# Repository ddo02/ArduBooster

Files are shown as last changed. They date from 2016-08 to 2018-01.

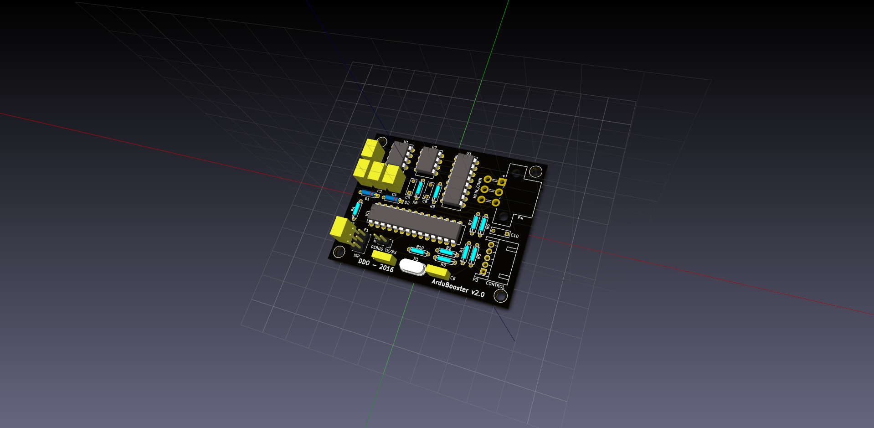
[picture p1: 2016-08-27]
3D_board.png

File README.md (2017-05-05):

# ArduBooster
TODO: Write the readme!

ArduBooster repository.

# License
This project is under dual-license.

First license is for commercial use of this project. To build a product, based on this project, and sell it.

Second license is for non-commercial use of this project. To build a sample, to personal use or education use.

# Donate


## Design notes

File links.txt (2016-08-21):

Arduino - AnalogWrite
https://www.arduino.cc/en/Reference/analogWrite

Arduino - Switch
https://www.arduino.cc/en/tutorial/switch

Arduino Tutorial - Lesson 3 - Breadboards and LEDs
http://www.ladyada.net/learn/arduino/lesson3.html

Arduino - Blink
https://www.arduino.cc/en/Tutorial/Blink?from=Tutorial.BlinkingLED

Fast PWM DAC
http://www.avdweb.nl/arduino/libraries/fast-pwm-dac.html

Arduino Playground - Timer1
http://playground.arduino.cc/code/timer1

Google Code Archive - Long-term storage for Google Code Project Hosting.
https://code.google.com/archive/p/arduino-timerone/

Analog Output - Convert PWM to Voltage - All
http://www.instructables.com/id/Analog-Output-Convert-PWM-to-Voltage/

Arduino’s AnalogWrite – Converting PWM to a Voltage
http://provideyourown.com/2011/analogwrite-convert-pwm-to-voltage/

(Sample)RC Low-pass Filter Design for PWM - Result -
http://sim.okawa-denshi.jp/en/PWMtool.php

Google
https://www.google.com.br/webhp?sourceid=chrome-instant&ion=1&espv=2&ie=UTF-8#q=diy+sprintbooster

www.crosslake.net/~dbipes/sprintbooster/SprintBooster.pdf
http://www.crosslake.net/~dbipes/sprintbooster/SprintBooster.pdf

Arduino - Map
https://www.arduino.cc/en/reference/map

map to floating point
http://forum.arduino.cc/index.php/topic=3922.0

connector sicma 4 vias - Pesquisa Google
https://www.google.com.br/search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

Cabex
http://www.cabex.com.br/produto/detalhe/id/83

404 Not Found
http://www.bmcom.com.br/lojas/papinjetores/produto.php?produto=1226

TC 104.1234 - TC Chicotes - Unitário | Canal da Peça
https://www.canaldapeca.com.br/p/1106702/tc-1041234-tc-chicotes-unitario

sprint-booster-circuit.jpg (660×469)
http://www.sprintbooster.ca/images/sprint-booster-circuit.jpg

www.intersil.com/content/dam/Intersil/documents/icl7/icl7660.pdf
http://www.intersil.com/content/dam/Intersil/documents/icl7/icl7660.pdf

Transistor Tutorial, history, sample circuits
http://www.sentex.ca/~mec1995/tutorial/xtor/xtor2/xtor2.html

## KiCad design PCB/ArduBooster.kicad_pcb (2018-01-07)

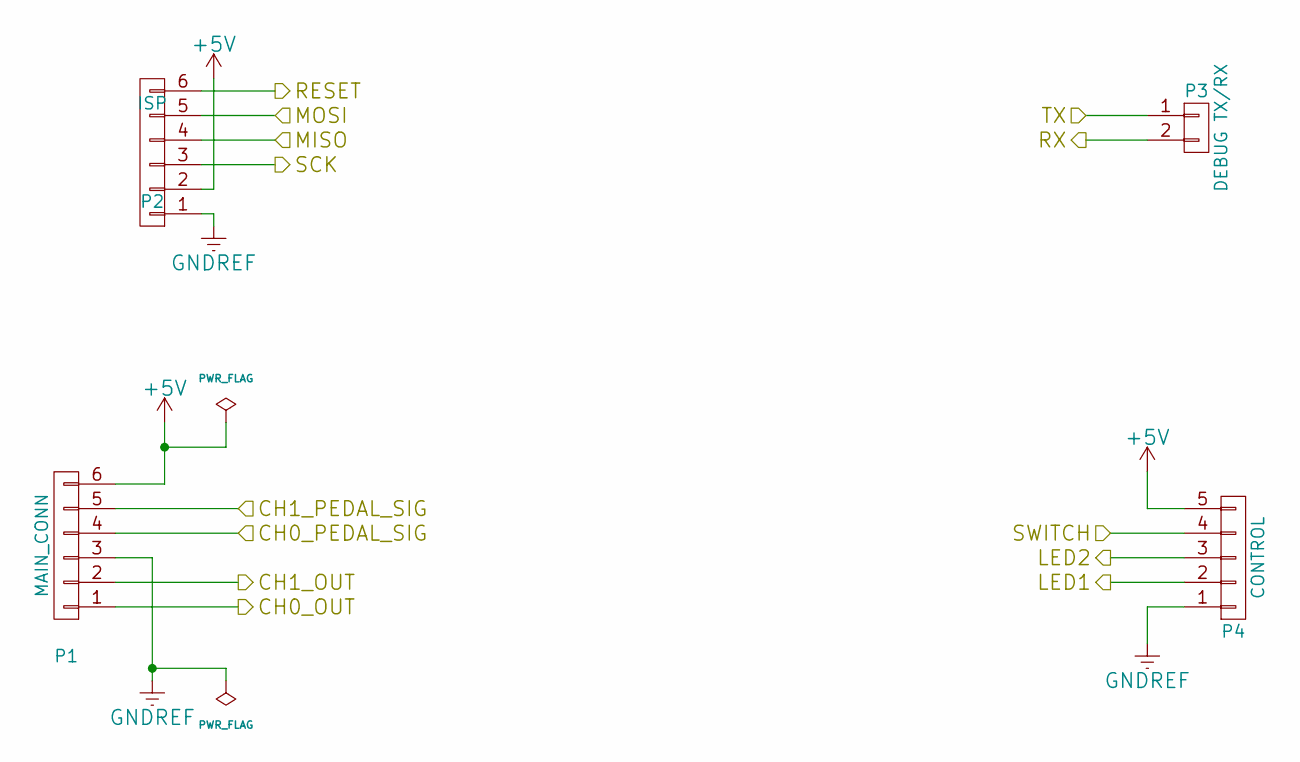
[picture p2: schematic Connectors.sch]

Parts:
P1: MAIN_CONN; Molex_MiniFit-JR-5569-06A1_2x03x4.20mm_Angled
P2: ISP; Pin_Header_Straight_1x06_Pitch2.54mm
P3: DEBUG TX/RX; Pin_Header_Straight_1x02_Pitch2.54mm
P4: CONTROL; Wafer_Horizontal15x5.8x7RM2.5-5

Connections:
+5V: P1.6, P2.2, P4.5; also elsewhere on the board
/Base Arduino/CH0_OUT: P1.1; also elsewhere on the board
/Base Arduino/CH0_PEDAL_SIG: P1.4; also elsewhere on the board
/Base Arduino/CH1_OUT: P1.2; also elsewhere on the board
/Base Arduino/CH1_PEDAL_SIG: P1.5; also elsewhere on the board
/Base Arduino/LED1: P4.2; also elsewhere on the board
/Base Arduino/LED2: P4.3; also elsewhere on the board
/Base Arduino/MISO: P2.4; also elsewhere on the board
/Base Arduino/MOSI: P2.5; also elsewhere on the board
/Base Arduino/RESET: P2.6; also elsewhere on the board
/Base Arduino/RX: P3.2; also elsewhere on the board
/Base Arduino/SCK: P2.3; also elsewhere on the board
/Base Arduino/SWITCH: P4.4; also elsewhere on the board
/Base Arduino/TX: P3.1; also elsewhere on the board
GNDREF: P1.3, P2.1, P4.1; also elsewhere on the board

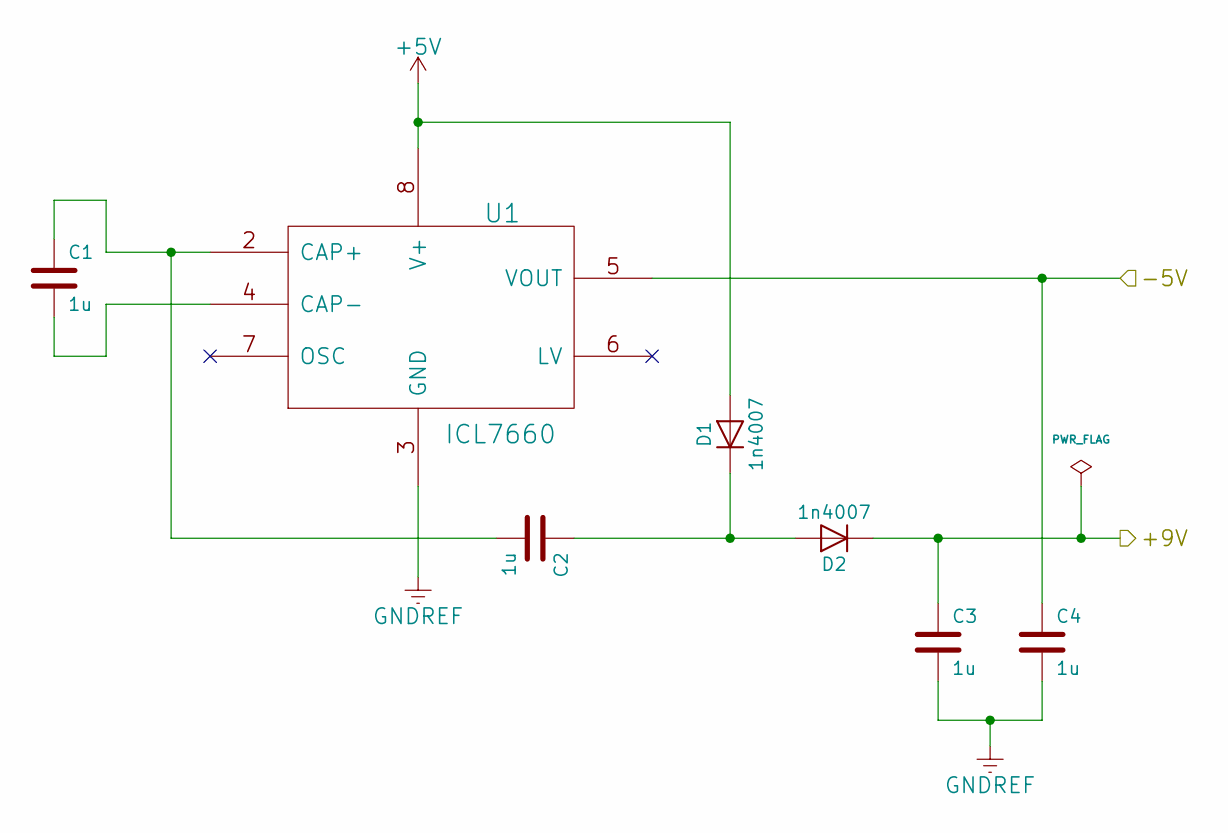
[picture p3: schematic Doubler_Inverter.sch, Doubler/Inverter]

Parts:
C1, C2, C3, C4: 1u; C_Rect_L7.0mm_W4.5mm_P5.00mm
D1, D2: 1n4007; D_A-405_P2.54mm_Vertical_AnodeUp
U1: ICL7660; DIP-8_W7.62mm_LongPads

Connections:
+5V: D1.2 (A), U1.8 (V+); also elsewhere on the board
/Doubler_Inverter/+9V: C3.1, D2.1 (K); also elsewhere on the board
/Doubler_Inverter/-5V: C4.1, U1.5 (VOUT); also elsewhere on the board
GNDREF: C3.2, C4.2, U1.3 (GND); also elsewhere on the board
unnamed: C1.1, C2.2, U1.2 (CAP+)
unnamed: C1.2, U1.4 (CAP-)
unnamed: C2.1, D1.1 (K), D2.2 (A)

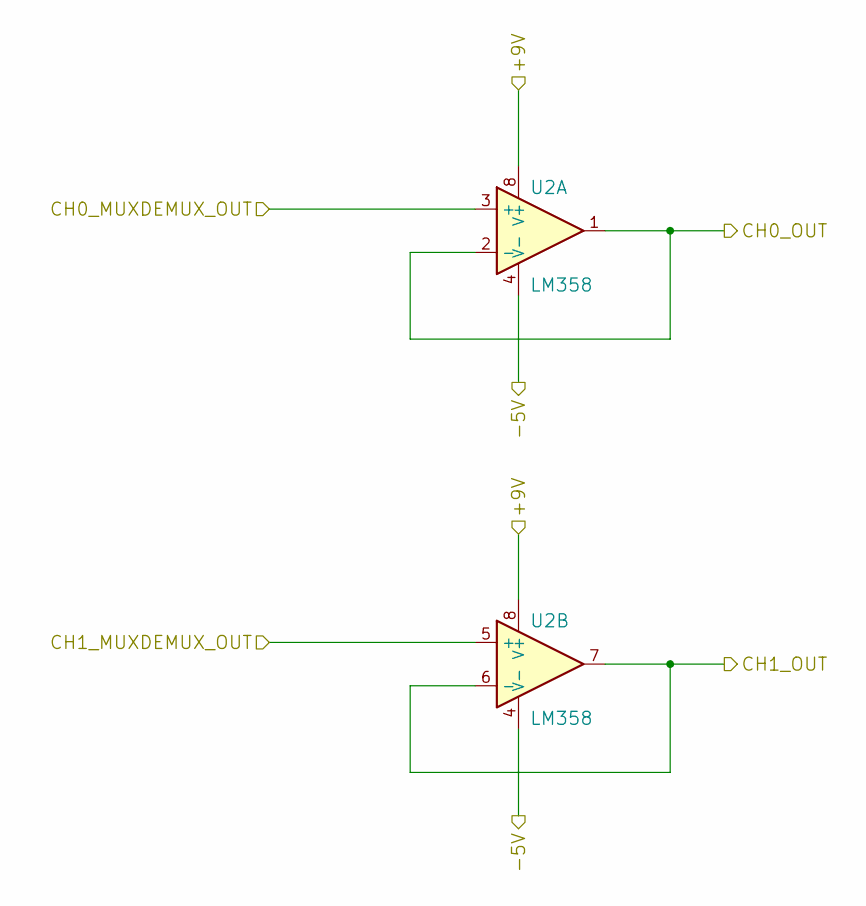
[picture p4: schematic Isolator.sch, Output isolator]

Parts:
U2: LM358; DIP-8_W7.62mm_LongPads

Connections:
/Base Arduino/CH0_OUT: U2.1, U2.2 (-); also elsewhere on the board
/Base Arduino/CH1_OUT: U2.6 (-), U2.7; also elsewhere on the board
/Doubler_Inverter/+9V: U2.8 (V+); also elsewhere on the board
/Doubler_Inverter/-5V: U2.4 (V-); also elsewhere on the board
/Isolator/CH0_MUXDEMUX_OUT: U2.3 (+); also elsewhere on the board
/Isolator/CH1_MUXDEMUX_OUT: U2.5 (+); also elsewhere on the board

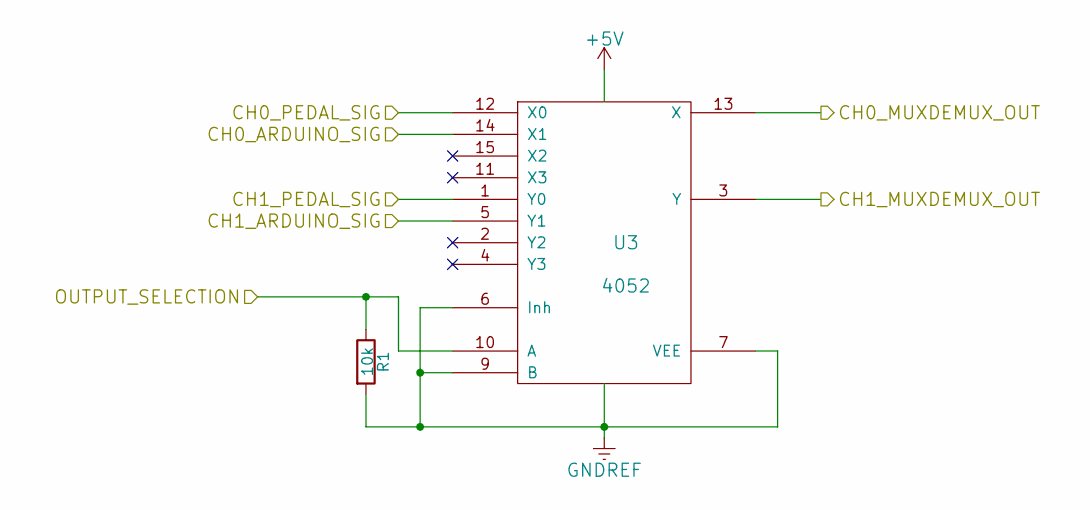
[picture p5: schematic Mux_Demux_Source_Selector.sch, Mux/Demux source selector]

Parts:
R1: 10k; R_Axial_DIN0207_L6.3mm_D2.5mm_P2.54mm_Vertical
U3: 4052; DIP-16_W7.62mm_LongPads

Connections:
+5V: U3.16 (VDD); also elsewhere on the board
/Base Arduino/CH0_ARDUINO_SIG: U3.14 (X1); also elsewhere on the board
/Base Arduino/CH0_PEDAL_SIG: U3.12 (X0); also elsewhere on the board
/Base Arduino/CH1_ARDUINO_SIG: U3.5 (Y1); also elsewhere on the board
/Base Arduino/CH1_PEDAL_SIG: U3.1 (Y0); also elsewhere on the board
/Base Arduino/MOSI: R1.1, U3.10 (A); also elsewhere on the board
/Isolator/CH0_MUXDEMUX_OUT: U3.13 (X); also elsewhere on the board
/Isolator/CH1_MUXDEMUX_OUT: U3.3 (Y); also elsewhere on the board
GNDREF: R1.2, U3.6 (Inh), U3.7 (VEE), U3.8 (VSS), U3.9 (B); also elsewhere on the board

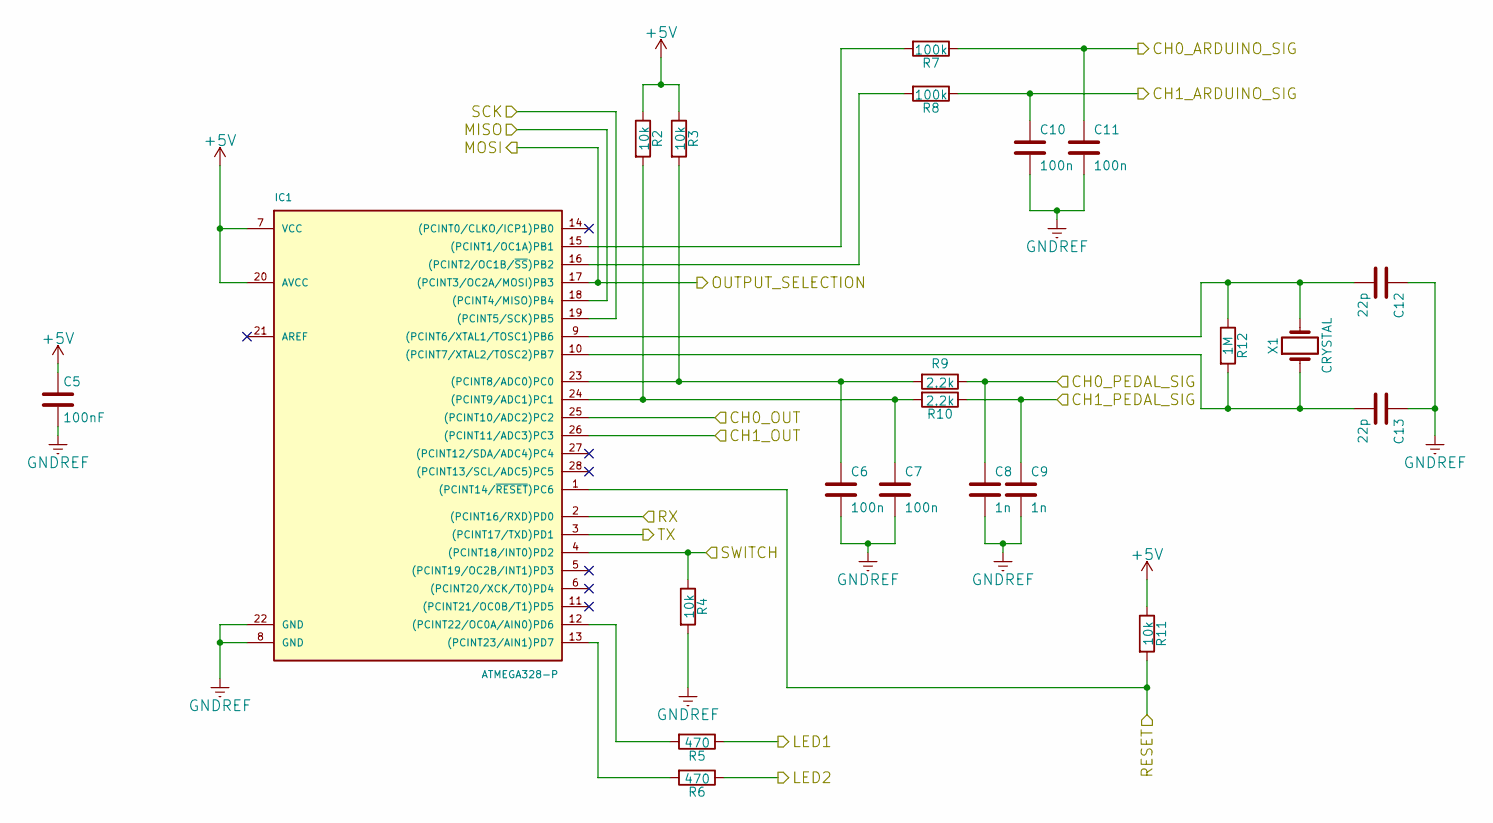
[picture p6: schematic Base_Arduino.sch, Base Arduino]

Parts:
C5: 100nF; C_Rect_L7.0mm_W2.5mm_P5.00mm
C6, C7, C10, C11: 100n; C_Rect_L7.0mm_W2.5mm_P5.00mm
C8, C9: 1n; C_Rect_L7.0mm_W2.0mm_P5.00mm
C12, C13: 22p; C_Rect_L7.0mm_W2.0mm_P5.00mm
IC1: ATMEGA328-P; DIP-28_W7.62mm_LongPads
R2, R3, R4, R11: 10k; R_Axial_DIN0207_L6.3mm_D2.5mm_P2.54mm_Vertical
R5, R6: 470; R_Axial_DIN0207_L6.3mm_D2.5mm_P2.54mm_Vertical
R7, R8: 100k; R_Axial_DIN0207_L6.3mm_D2.5mm_P2.54mm_Vertical
R9, R10: 2.2k; R_Axial_DIN0207_L6.3mm_D2.5mm_P7.62mm_Horizontal
R12: 1M; R_Axial_DIN0207_L6.3mm_D2.5mm_P2.54mm_Vertical
X1: CRYSTAL; Crystal_HC49-U_Vertical

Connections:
+5V: C5.1, IC1.7 (VCC), IC1.20 (AVCC), R2.1, R3.1, R11.1; also elsewhere on the board
/Base Arduino/CH0_ARDUINO_SIG: C11.1, R7.1; also elsewhere on the board
/Base Arduino/CH0_OUT: IC1.25 ((PCINT10/ADC2)PC2); also elsewhere on the board
/Base Arduino/CH0_PEDAL_SIG: C8.1, R9.1; also elsewhere on the board
/Base Arduino/CH1_ARDUINO_SIG: C10.1, R8.1; also elsewhere on the board
/Base Arduino/CH1_OUT: IC1.26 ((PCINT11/ADC3)PC3); also elsewhere on the board
/Base Arduino/CH1_PEDAL_SIG: C9.1, R10.1; also elsewhere on the board
/Base Arduino/LED1: R5.1; also elsewhere on the board
/Base Arduino/LED2: R6.1; also elsewhere on the board
/Base Arduino/MISO: IC1.18 ((PCINT4/MISO)PB4); also elsewhere on the board
/Base Arduino/MOSI: IC1.17 ((PCINT3/OC2A/MOSI)PB3); also elsewhere on the board
/Base Arduino/RESET: IC1.1 ((PCINT14/~RESET~)PC6), R11.2; also elsewhere on the board
/Base Arduino/RX: IC1.2 ((PCINT16/RXD)PD0); also elsewhere on the board
/Base Arduino/SCK: IC1.19 ((PCINT5/SCK)PB5); also elsewhere on the board
/Base Arduino/SWITCH: IC1.4 ((PCINT18/INT0)PD2), R4.1; also elsewhere on the board
/Base Arduino/TX: IC1.3 ((PCINT17/TXD)PD1); also elsewhere on the board
GNDREF: C5.2, C6.2, C7.2, C8.2, C9.2, C10.2, C11.2, C12.1, C13.1, IC1.8 (GND), IC1.22 (GND), R4.2; also elsewhere on the board
unnamed: C6.1, IC1.23 ((PCINT8/ADC0)PC0), R3.2, R9.2
unnamed: C7.1, IC1.24 ((PCINT9/ADC1)PC1), R2.2, R10.2
unnamed: C12.2, IC1.9 ((PCINT6/XTAL1/TOSC1)PB6), R12.1, X1.2
unnamed: C13.2, IC1.10 ((PCINT7/XTAL2/TOSC2)PB7), R12.2, X1.1
unnamed: IC1.12 ((PCINT22/OC0A/AIN0)PD6), R5.2
unnamed: IC1.13 ((PCINT23/AIN1)PD7), R6.2
unnamed: IC1.15 ((PCINT1/OC1A)PB1), R7.2
unnamed: IC1.16 ((PCINT2/OC1B/~SS~)PB2), R8.2

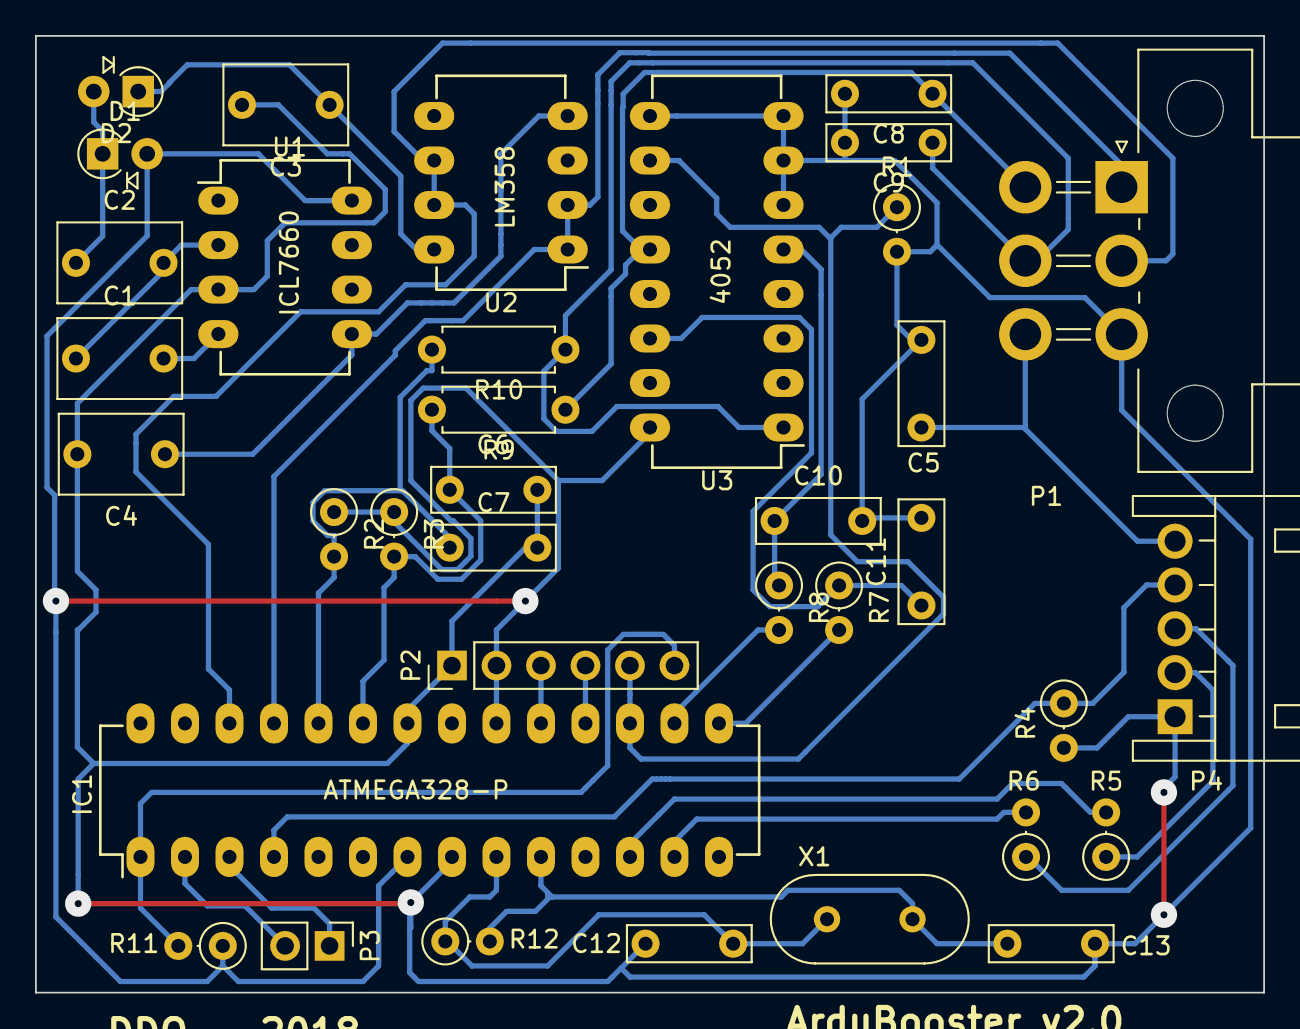
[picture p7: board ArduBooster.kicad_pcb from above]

Board: 2 copper layers, 70.1 x 54.6 mm, 36 parts (0 on the bottom side), 32 nets.

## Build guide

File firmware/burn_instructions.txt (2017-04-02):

Instructions to burn firmware on ArduBooster v1.0 board:

- Using an Arduino Uno (or compatible) board as a burner, to upload firmware to ArduBooster (Arduino as USB-to-Serial).
- Remove uC from Arduino board.
- Wire ArduBooster reset pin to Arduino reset pin.
- Wire ArduBooster Tx to Arduino Rx.
- Wire ArduBooster Rx to Arduino Tx.
- Connect Arduino Gnd and 5V to ArduBooster.
- On Arduino IDE, select the board according to used on ArduBooster (Arduino Uno recommended).
- BURN!!!

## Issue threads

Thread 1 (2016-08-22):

Small input pull up resistor

ddo02, 2016-08-22:
The used input pull up resistor (10k) can be small if working with POT sensor (works well with hall sensor).

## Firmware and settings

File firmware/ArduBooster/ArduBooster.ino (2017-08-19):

#include <EEPROM.h>
#include <avr/wdt.h>

#include "Filters.h"

// TODO LIST:
// Support to pedal with inverted signal (sensor 1 increase and sensor 2 decrease or vice-versa)
// Tests with POT pedal sensor
// Detect POT or HALL
// Use internal pull-up
// Auto find min sensor value (today, is readed is setup function)
// *OK* Enable watchdog * WD enabled
// *OK* Lower engineering margin :) (10% to 5% [?]) * 7%
// *NOK* Save max pesal value * This can be a problem, if change the car
// *NOK* Bypass when on idle * Not needed with PWM 10 bits

/** DEBUG FRAGS ***********************************************************************************/

// Enable/Disable serial debug
const bool DEBUG = false;

// Debug timer counter
unsigned int dbg_time_count = 0;
const unsigned long dbg_time = 50; // loops

/** END DEBUG FRAGS *******************************************************************************/

/** CONSTANTS *************************************************************************************/

// Boost mode 1 correction values (to use with map function)
const int MODE_1_MIN = 0;
const int MODE_1_MAX = 1535; // 50% (1023 to 1535)

// Boost mode 2 correction values (to use with map function)
const int MODE_2_MIN = 0;
const int MODE_2_MAX = 2046; // 100% (1023 to 2046)

// Max value to PWM
const int MAX_PWM = 1023;

// Number of times that ADC (sig0 and sig1) will be read to make a mean
const int BASE_VALUES_LOOP_COUNT = 10;

// Input signal pins, to read pedal position
const int sensorPot0Pin = A0;
const int sensorPot1Pin = A1;

// Feedback signal pins, to read and correct output signal
const int outputFeedback0Pin = A2;
const int outputFeedback1Pin = A3;

// Led mode pins
const int ledPin0 = 6;
const int ledPin1 = 7;

// Output signal pins
const int output0Pin = 9;
const int output1Pin = 10;

// Button pin (used to change boost mode)
const int buttonModePin = 2;

// Control pin, to enable/disable mux
const int enableMuxPin = 11;

const float filterCutFrequency = 100; // Hz

/** END CONSTANTS *********************************************************************************/

/** VARIABLES *************************************************************************************/

// Pedal values
int sensorPot0Value = 0;
int sensorPot1Value = 0;

// Maximum pedal value readed
int sensorPot0ValueMax = 0;
int sensorPot1ValueMax = 0;

// Output boost values
int output0Value = 0;
int output1Value = 0;

// Minimum pedal value, used to disable boost when the pedal is idle
int sensorPot0CutValue = 0;
int sensorPot1CutValue = 0;
int sensorPot0IdleValue = 0;
int sensorPot1IdleValue = 0;

// Proportion between sig0 and sig1
// Used to validate subsequent read
float sig_021_proportion = 2.0;

double first_vcc;
double current_vcc;

// Current boost mode
// 0 -> original
// 1 -> boost 1 (50%)
// 2 -> boost 2 (100%)
int mode = 0;

// Flag to determine if sensor is hall or not (potentiometer)
bool is_hall_sensor = true;

bool need_final_init = false;
bool need_find_sensor_type = false;

bool testing_sensor_0 = false;
bool testing_sensor_1 = false;

//FilterOnePole filter_pot_0(LOWPASS, filterCutFrequency);
//FilterOnePole filter_pot_1(LOWPASS, filterCutFrequency);

/** END VARIABLES *********************************************************************************/

/** METHODS ***************************************************************************************/

/*
Configure digital pins 9 and 10 as 10-bit PWM outputs.
With this config, PWM frequency is about 15khz
*/
void setupPWM10bits() {
  
  Serial.println("Starting PWM 10-bit...");
  
  DDRB |= _BV(PB1) | _BV(PB2);        // Set pins as outputs
  TCCR1A = _BV(COM1A1) | _BV(COM1B1)  // Non-inverting PWM
      | _BV(WGM11);                   // Mode 14: fast PWM, TOP=ICR1
  TCCR1B = _BV(WGM13) | _BV(WGM12)
      | _BV(CS10);                    // No prescaling
  ICR1 = 0x400;                       // TOP counter value (1024/10bits)
}

/*
After configured (using setupPWM10bits function), 
use this function to write PWM 10-bit
*/
void analogWrite10b(uint8_t pin, uint16_t val) {
    switch (pin) {
        case  9: OCR1A = val; break;
        case 10: OCR1B = val; break;
    }
}

void readIdleValues() {
  
  // Calculate initial idle pedal position
  // To avoid boost when pedal is not pressed
  // TODO: auto find idle position
  
  unsigned int adc_0_sum = 0;
  unsigned int adc_1_sum = 0;
  
  for(int i=0; i<BASE_VALUES_LOOP_COUNT; i++) {
    adc_0_sum += analogRead(sensorPot0Pin);
    adc_1_sum += analogRead(sensorPot1Pin);
  }
  
  sensorPot0IdleValue = (adc_0_sum / BASE_VALUES_LOOP_COUNT);
  sensorPot1IdleValue = (adc_1_sum / BASE_VALUES_LOOP_COUNT);
  
  // Engineering margin of safety :)
  // TODO: smooth transition
  //sensorPot0CutValue = adc_0_val * 1.05;
  //sensorPot1CutValue = adc_1_val * 1.05;
  
  // Sig1 to sig2 proportion
  // Theoretically, sensorPot1IdleValue (or sensorPot0IdleValue) never will be zero
  sig_021_proportion = sensorPot0IdleValue / sensorPot1IdleValue;
  
  //Serial.println(adc_0_sum);
  //Serial.println(adc_1_sum);
  //Serial.println(sensorPot0IdleValue);
  //Serial.println(sensorPot1IdleValue);
  //Serial.println(sig_021_proportion);
}

/*
Change mux/demux to use arduino signal
*/
void enableBoost() {

  // First of all
  // Verifies if PWM output RC filter had time enough to get correct value
  // To current RC values (R=100k and C=100n, with 15KHz), this time is about 25ms
  
  static unsigned long firstTime = millis();
  static bool boostEnabled = false;
  unsigned long timeToRC = 25; //ms
  if(!boostEnabled && firstTime + timeToRC < millis()) {
    digitalWrite(enableMuxPin, HIGH);
    boostEnabled = true;
  }
}

/*
void initOutput() {
  
  // Only (at setup) put the input value to output pin
  // This will improves the PID
  
  sensorPot0Value = analogRead(sensorPot0Pin);
  sensorPot1Value = analogRead(sensorPot1Pin);
  
  output0Value = map(sensorPot0Value, 0, 1023, 0, MAX_PWM);
  output1Value = map(sensorPot1Value, 0, 1023, 0, MAX_PWM);
  
  analogWrite10b(output0Pin, output0Value);
  analogWrite10b(output1Pin, output1Value);
}
*/

/*
Find sensor type.
Potentiometer or hall effect (open collector)

*** TO USE THIS, NEED HARDWARE MODIFICATION. DESABLE EXTERNAL PULL-UPS ***
*/
void findSensorType() {
  
  Serial.println("Finding sensor type...");
  
  // pull-down
  pinMode(sensorPot0Pin, OUTPUT);
  pinMode(sensorPot1Pin, OUTPUT);
  digitalWrite(sensorPot0Pin, LOW);
  digitalWrite(sensorPot1Pin, LOW);
  
  sensorPot0Value = analogRead(sensorPot0Pin);
  sensorPot1Value = analogRead(sensorPot1Pin);
  
  //TODO: constant
  if(sensorPot0Value <= 20 && sensorPot1Value <= 20) {
    is_hall_sensor = true;
    
    pinMode(sensorPot0Pin, INPUT_PULLUP);
    pinMode(sensorPot1Pin, INPUT_PULLUP);
  } else {
    is_hall_sensor = false;
    pinMode(sensorPot0Pin, INPUT);
    pinMode(sensorPot1Pin, INPUT);
  }
  
  Serial.print("Sensor 0: ");
  Serial.println(sensorPot0Value);
  Serial.print("Sensor 1: ");
  Serial.println(sensorPot1Value);
  
  if(is_hall_sensor)
    Serial.println("HALL SENSOR");
  else
    Serial.println("POT SENSOR");
}

ISR(ADC_vect)
{
} 

/*
Arduino setup
*/
void setup() {

  //analogReference(INTERNAL);
  
  // Enable ADC interrupt (call function ISR)
  //ADCSRA |= B00001000;
  
  // Init serial debug
  Serial.begin(9600);
  
  Serial.println("ArduBooster v2.0");
  Serial.println("Starting ArduBooster...");
  
  // Configure some pins
  pinMode(ledPin0, OUTPUT);  
  pinMode(ledPin1, OUTPUT);
  pinMode(output0Pin, OUTPUT);
  pinMode(output1Pin, OUTPUT);
  pinMode(buttonModePin, INPUT);
  pinMode(enableMuxPin, OUTPUT);
  
  //findSensorType();
  readIdleValues();

  first_vcc = readVcc()/1000.0;
  current_vcc = first_vcc;
  
  // TODO: 1.07 constant
  sensorPot0CutValue = sensorPot0IdleValue * 1.07;
  sensorPot1CutValue = sensorPot1IdleValue * 1.07;
  
  // Init PWM 10-bit
  setupPWM10bits();

  // Blink leds (initial boot)
  showBoot();
  
  // Load saved working mode
  mode = readMode();
  // Show working mode
  showMode(mode);
  
  Serial.println("ArduBooster started!");
  Serial.println("Enabling WD! Bye!!!");
  
  wdt_enable(WDTO_15MS);
}

// Arduino main loop
void loop() {
  
  //Serial.println(mode);

  
  //ADCValue = analogRead(0);
  //Voltage = (ADCValue / 1024.0) * Vcc;

  // read pedal values (0-1023)
  sensorPot0Value = analogRead(sensorPot0Pin);
  sensorPot1Value = analogRead(sensorPot1Pin);

  //Serial.println("=========");
  //Serial.println(sensorPot0Value);
  //Serial.println(sensorPot1Value);
  
  // TODO: delay problem???
  static int vcc_pass_count = 0;
  vcc_pass_count++;
  if (vcc_pass_count > 50) {
    //current_vcc = readVcc()/1000.0;
    vcc_pass_count = 0;
  }
  //sensorPot0Value = (sensorPot0Value * first_vcc) / current_vcc;
  //sensorPot1Value = (sensorPot1Value * first_vcc) / current_vcc;

  //Serial.println(first_vcc);
  //Serial.println(Vcc);
  //Serial.println(sensorPot0Value);
  //Serial.println(sensorPot1Value);
  //Serial.println("=========");
  
  //filter_pot_0.input(analogRead(sensorPot0Pin));
  //filter_pot_1.input(analogRead(sensorPot1Pin));
  //sensorPot0Value = filter_pot_0.output();
  //sensorPot1Value = filter_pot_1.output();
  
  // Compute max read value
  if (sensorPot0Value > sensorPot0ValueMax) {
    sensorPot0ValueMax = sensorPot0Value;
  }
  if (sensorPot1Value > sensorPot1ValueMax) {
    sensorPot1ValueMax = sensorPot1Value;
  }

  //TODO: Change this code to an interrupt
  //TODO: Need a small cap, to avoid multi interrupt fire
  // read button mode
  int buttonModeState = digitalRead(buttonModePin);
  // if pressed, change the boost mode
  static boolean pressed = false;
  if (buttonModeState == HIGH) {
    if(!pressed) {
      pressed = true;
      // Change to next boost mode
      mode = nextMode();
      showMode(mode);
    }
  } else {
    pressed = false;
  }
  
  //Serial.println(mode);
  //Serial.println("Sensor 0: ");
  //Serial.println(sensorPot0Value);
  //Serial.println("Sensor 1: ");
  //Serial.println(sensorPot1Value);

  //Serial.println("Cut 0: ");
  //Serial.println(sensorPot0CutValue);
  //Serial.println("Cut 1: ");
  //Serial.println(sensorPot1CutValue);
  //Serial.println();
  
  // Boost mode 1 (check if pedal is not in idle position, too)
  if(mode == 1 && sensorPot0Value > sensorPot0CutValue && sensorPot1Value > sensorPot1CutValue) {
    
    //Serial.println("BOOST 1");
    
    // Apply boost mode 1 correction
    
    int tmpOut0 = map(sensorPot0Value, 0, 1023, MODE_1_MIN, MODE_1_MAX);
    int tmpOut1 = map(sensorPot1Value, 0, 1023, MODE_1_MIN, MODE_1_MAX);
    
    // Veryfies if the corrected value isnt too big or too small
    // If the value is more than ECU max value (or min value), the ECU can put the engine in safe mode
    if (tmpOut0 > sensorPot0ValueMax) {
      tmpOut0 = sensorPot0ValueMax;
    }
    if (tmpOut1 > sensorPot1ValueMax) {
      tmpOut1 = sensorPot1ValueMax;
    }
    if (tmpOut0 < sensorPot0IdleValue) {
      tmpOut0 = sensorPot0IdleValue;
    }
    if (tmpOut1 < sensorPot1IdleValue) {
      tmpOut1 = sensorPot1IdleValue;
    }
    
    // Prepare to PWM
    output0Value = map(tmpOut0, 0, 1023, 0, MAX_PWM);
    output1Value = map(tmpOut1, 0, 1023, 0, MAX_PWM);
  } 
  // Boost mode 2 (check if pedal is not in idle position, too)
  else if(mode == 2 && sensorPot0Value > sensorPot0CutValue && sensorPot1Value > sensorPot1CutValue) {
    
    //Serial.println("BOOST 2");
    
    // Apply boost mode 2 correction
    
    int tmpOut0 = map(sensorPot0Value, 0, 1023, MODE_2_MIN, MODE_2_MAX);
    int tmpOut1 = map(sensorPot1Value, 0, 1023, MODE_2_MIN, MODE_2_MAX);

    //Serial.println("TPM 0: ");
    //Serial.println(tmpOut0);
    //Serial.println("TMP 1: ");
    //Serial.println(tmpOut1);

    // Veryfies if the corrected value isnt too big or too small
    // If the value is more than ECU max value (or min value), the ECU can put the engine in safe mode
    if (tmpOut0 > sensorPot0ValueMax) {
      tmpOut0 = sensorPot0ValueMax;
    }
    if (tmpOut1 > sensorPot1ValueMax) {
      tmpOut1 = sensorPot1ValueMax;
    }
    if (tmpOut0 < sensorPot0IdleValue) {
      tmpOut0 = sensorPot0IdleValue;
    }
    if (tmpOut1 < sensorPot1IdleValue) {
      tmpOut1 = sensorPot1IdleValue;
    }
    
    // Prepare to PWM
    output0Value = map(tmpOut0, 0, 1023, 0, MAX_PWM);
    output1Value = map(tmpOut1, 0, 1023, 0, MAX_PWM);
    
  } 
  // Boost mode 0 (no boost) or pedal is in idle position
  else {
    
    //Serial.println("BOOST 0");
    
    output0Value = map(sensorPot0Value, 0, 1023, 0, MAX_PWM);
    output1Value = map(sensorPot1Value, 0, 1023, 0, MAX_PWM);
    
  }
  
  //TODO: debug only
  if(sensorPot0Value > sensorPot0CutValue && sensorPot1Value > sensorPot1CutValue) {
    showNotIdle();
  } else {
    showMode(mode);
  }
  
  // Normalizes output
  if(output0Value > MAX_PWM) {
    output0Value = MAX_PWM; 
  }
  if(output1Value > MAX_PWM) {
    output1Value = MAX_PWM; 
  }
  if(output0Value < 0) {
    output0Value = 0; 
  }
  if(output1Value < 0) {
    output1Value = 0; 
  }

  //Serial.println(output0Value);
  //Serial.println(output1Value);
  //Serial.println();
    
  analogWrite10b(output0Pin, output0Value);
  analogWrite10b(output1Pin, output1Value);
  
  // Watchdog reset
  wdt_reset();
  
  enableBoost();
}

// Verifies if show debug in this execution loop
bool isShowTime() {
  return dbg_time_count == dbg_time;
}

long readVcc() {
  long result;
  // Read 1.1V reference against AVcc
  ADMUX = _BV(REFS0) | _BV(MUX3) | _BV(MUX2) | _BV(MUX1);
  delay(2); // Wait for Vref to settle
  ADCSRA |= _BV(ADSC); // Convert
  while (bit_is_set(ADCSRA,ADSC));
  result = ADCL;
  result |= ADCH<<8;
  result = 1125300L / result; // Back-calculate AVcc in mV
  return result;
}

// Change to next mode and store in eeprom
int nextMode() {
  
  int newVal = mode + 1;
  if(newVal > 2) {
    newVal = 0;
  }
  EEPROM.write(0, newVal);
  
  return newVal;
}

// Read mode from eeprom
int readMode() {
  int value = EEPROM.read(0);
  
  if(value > 2) {
    value = 0;
  }
  
  return value;
}

// Blink at startup
void showBoot() {
  
  digitalWrite(ledPin0, HIGH);   
  digitalWrite(ledPin1, HIGH);
  delay(100);
  digitalWrite(ledPin0, LOW);   
  digitalWrite(ledPin1, LOW);
  delay(100);
  digitalWrite(ledPin0, HIGH);   
  digitalWrite(ledPin1, HIGH);
  delay(100);
  digitalWrite(ledPin0, LOW);   
  digitalWrite(ledPin1, LOW);
  delay(100);
  
}

// Show current mode with leds
void showMode(int mode) {
  
  // TODO: use switch
  if(mode == 0) {
    digitalWrite(ledPin0, LOW);   
    digitalWrite(ledPin1, LOW);
  } else if(mode == 1) {
    digitalWrite(ledPin0, HIGH);   
    digitalWrite(ledPin1, LOW);
  } else if(mode == 2) {
    digitalWrite(ledPin0, LOW);   
    digitalWrite(ledPin1, HIGH);
  }
}

void showNotIdle() {
  digitalWrite(ledPin0, HIGH);   
  digitalWrite(ledPin1, HIGH);
}

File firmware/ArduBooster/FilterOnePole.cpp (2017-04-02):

#include "FilterOnePole.h"
//#include "FloatDefine.h"

FilterOnePole::FilterOnePole( FILTER_TYPE ft, float fc, float initialValue ) {
  setFilter( ft, fc, initialValue );
}

void FilterOnePole::setFilter( FILTER_TYPE ft, float fc, float initialValue ) {
  FT = ft;
  setFrequency( fc );

  Y = initialValue;
  Ylast = initialValue;
  X = initialValue;

  LastUS = micros();
}

float FilterOnePole::input( float inVal ) {
  long time = micros();
  ElapsedUS = float(time - LastUS);   // cast to float here, for math
  LastUS = time;                      // update this now

  // shift the data values
  Ylast = Y;
  X = inVal;                          // this is now the most recent input value
  
  // filter value is controlled by a parameter called X
  // tau is set by the user in microseconds, but must be converted to samples here
  TauSamps = TauUS / ElapsedUS;
  
  float ampFactor;
#ifdef ARM_FLOAT
  ampFactor = expf( -1.0 / TauSamps );     // this is 1 if called quickly
#else
  ampFactor = exp( -1.0 / TauSamps );      // this is 1 if called quickly
#endif
  
  Y = (1.0-ampFactor)*X + ampFactor*Ylast;     // set the new value

  return output();
}

void FilterOnePole::setFrequency( float newFrequency ) {
  setTau( 1.0/(TWO_PI*newFrequency ) ); // τ=1/ω
}

void FilterOnePole::setTau( float newTau ) {
  TauUS = newTau * 1e6;
}

float FilterOnePole::output() {
    // figure out which button to read
  switch (FT) {
    case LOWPASS:         
      // return the last value
      return Y; 
      break;
    case INTEGRATOR:      
      // using a lowpass, but normaize
      return Y * (TauUS/1.0e6);
      break;
    case HIGHPASS:       
      // highpass is the _difference_
      return X-Y;
      break;
    case DIFFERENTIATOR:
      // like a highpass, but normalize
      return (X-Y)/(TauUS/1.0e6);
      break;
    default:
      // should never get to here, return 0 just in case
      return 0;
  }
}

void FilterOnePole::print() {
  Serial.println("");
  Serial.print(" Y: ");        Serial.print( Y );
  Serial.print(" Ylast: ");      Serial.print( Ylast );
  Serial.print(" X ");         Serial.print( X );
  Serial.print(" ElapsedUS ");  Serial.print( ElapsedUS );
  Serial.print(" TauSamps: ");  Serial.print( TauSamps );
  //Serial.print(" ampFactor " );       Serial.print( ampFactor );
  Serial.print(" TauUS: ");     Serial.print( TauUS );
  Serial.println("");
}

void FilterOnePole::test() {
  float tau = 10;
  float updateInterval = 1;
  float nextupdateTime = millis()*1e-3;

  float inputValue = 0;
  FilterOnePole hp( HIGHPASS, tau, inputValue );
  FilterOnePole lp( LOWPASS, tau, inputValue );

  while( true ) {
    float now = millis()*1e-3;

    // switch input values on a 20 second cycle
    if( round(now/20.0)-(now/20.0) < 0 )
    inputValue = 0;
    else
    inputValue = 100;

    hp.input(inputValue);
    lp.input(inputValue);

    if( now > nextupdateTime ) {
      nextupdateTime += updateInterval;

      Serial.print("inputValue: "); Serial.print( inputValue );
      Serial.print("\t high-passed: "); Serial.print( hp.output() );
      Serial.print("\t low-passed: "); Serial.print( lp.output() );
      Serial.println();
    }
  }
}

void FilterOnePole::setToNewValue( float newVal ) {
  Y = Ylast = X = newVal;
}


// stuff for filter2 (lowpass only)
// should be able to set a separate fall time as well
FilterOnePoleCascade::FilterOnePoleCascade( float riseTime, float initialValue ) {
  setRiseTime( riseTime );
  setToNewValue( initialValue );
}

void FilterOnePoleCascade::setRiseTime( float riseTime ) {
  float tauScale = 3.36;      // found emperically, by running test();

  Pole1.setTau( riseTime / tauScale );
  Pole2.setTau( riseTime / tauScale );
}

float FilterOnePoleCascade::input( float inVal  ) {
  Pole2.input( Pole1.input( inVal ));
  return output();
}

// clears out the values in the filter
void FilterOnePoleCascade::setToNewValue( float newVal ) {
  Pole1.setToNewValue( newVal );
  Pole2.setToNewValue( newVal );
}

float FilterOnePoleCascade::output() {
  return Pole2.output();
}

void FilterOnePoleCascade::test() {
  // make a filter, how fast does it run:
  
  float rise = 1.0;
  FilterOnePoleCascade myFilter( rise );
  
  // first, test the filter speed ...
  long nLoops = 1000;
  
  Serial.print( "testing filter with a rise time of ");
  Serial.print( rise ); Serial.print( "s" );
  
  Serial.print( "\n running filter speed loop ... ");
  
  float startTime, stopTime;
  
  startTime = millis()*1e-3;
  for( long i=0; i<nLoops; ++i ) {
    myFilter.input( PI );   // use pi, so it will actually do a full calculation
  }
  stopTime = millis()*1e-3;
  
  Serial.print( "done, filter runs at " );
  Serial.print( float(nLoops) / (stopTime - startTime) );
  Serial.print( " hz " );
  Serial.print( "\n filter value: " ); Serial.print( myFilter.output() );

  myFilter.setToNewValue( 0.0 );
  Serial.print( "\n after reset to 0: "); Serial.print( myFilter.output() );
  
  Serial.print( "\n testing rise time (10% to 90%) ...");
  
  bool crossedTenPercent = false;
  while( myFilter.output() < 0.9 ) {
    myFilter.input( 1.0 );
    if( myFilter.output() > 0.1 && !crossedTenPercent ) {
      // filter first crossed the 10% point
      startTime = millis()*1e-3;
      crossedTenPercent = true;
    }
  }
  stopTime = millis()*1e-3;
  
  Serial.print( "done, rise time: " ); Serial.print( stopTime-startTime );
  
  Serial.print( "testing attenuation at f = 1/risetime" );
  
  myFilter.setToNewValue( 0.0 );
  
  float maxVal = 0;
  float valWasOutputThisCycle = true;
  
  float lastFilterVal = 0;
  
  while( true ) {
    float now = 1e-3*millis();
    
    float currentFilterVal = myFilter.input( sin( TWO_PI*now) );

    if( currentFilterVal < 0.0 ) {
      if( !valWasOutputThisCycle ) {
        // just crossed below zero, output the max
        Serial.print( maxVal*100 ); Serial.print( " %\n" );
        valWasOutputThisCycle = true;
      }
      
    }
    
  }
  
    
  
}

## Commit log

2016-08-21 Initial Kicad project commit.
    [ArduBooster.dsn, ArduBooster.kicad_pcb, ArduBooster.sch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]
2016-08-22 Creating folder structure to work with Arduino IDE.
2016-08-22 TODO list Watchdog enabled (15ms) Blink leds at startup.
2016-08-23 Libraries and footprints adjustments. New connectors (4 pins main, 2 pins debug and 6 pins isp). New source input cap.
    [ArduBooster.sch, Base_Arduino.sch, Connectors.sch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]
2016-08-24 New connectors connection. Labels corrections (direction).
    [ArduBooster.sch, Base_Arduino.sch, Connectors.sch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]
2016-08-24 New connectors footprints. New .net file. New BoM file.
    [Connectors.sch]
2016-08-24 Correct DIP sockets footprints.
    [Base_Arduino.sch, Doubler_Inverter.sch, Isolator.sch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]
2016-08-24 Correct footprint main connector.
    [Connectors.sch]
2016-08-24 Initial new board route.
    [ArduBooster.kicad_pcb]
2016-08-24 First components placement.
    [ArduBooster.kicad_pcb]
2016-08-25 Output feedback.
    [Base_Arduino.sch]
2016-08-25 Optional crystal resistor.
    [Base_Arduino.sch, Connectors.sch, Doubler_Inverter.sch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]
2016-08-25 Resistor footprint.
    [Base_Arduino.sch, Connectors.sch, Doubler_Inverter.sch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]
2016-08-25 New crystal footprint. New route.
    [ArduBooster.dsn, ArduBooster.kicad_pcb, Base_Arduino.sch]
2016-08-26 Gerber and drill files
    [ArduBooster-B.Cu.gbl, ArduBooster-B.Fab.gbr, ArduBooster-B.SilkS.gbo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]
2016-08-26 New route, gerber files and drill files.
    [ArduBooster-B.Cu.gbl, ArduBooster-B.Fab.gbr, ArduBooster-B.SilkS.gbo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]
2016-08-26 Initial output feedback connection correction.
    [ArduBooster.sch, Base_Arduino.sch]
2016-08-27 Output feedback connection correction.
    [ArduBooster.dsn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]
2016-09-04 Initial PID class.
2016-09-04 Initial PID.
2016-10-02 PID tests PWM 10-bit Debug mode
2016-10-02 Changed DAC resistor to 100k (to works fine with new 10-bit PWM and new frenquency[15khz])
    [Base_Arduino.sch]
2016-10-13 ADC tests.
2016-10-14 ADC interrupt
2016-10-27 Find sensor type
2016-11-04 Added digital filter (from https://github.com/JonHub/Filters)
2017-04-02 Changed minimum throttle from 5% to 7%. DSP removed. Added a timer to start conversions. To wait output RC filter start.
2017-08-19 ADC corrections tests.
2018-01-07 Last commit before Mux/Demux removel. Single layer PCB incompete (3 wires). Add ADC input filter.
    [ArduBooster.dsn, ArduBooster.kicad_pcb, Base_Arduino.sch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]
